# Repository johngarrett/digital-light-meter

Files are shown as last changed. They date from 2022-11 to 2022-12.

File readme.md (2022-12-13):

# About

This project is a digital light meter used for metering photos. 
There were two goals in mind when building this:
1. Let the user track the camera settings for each shot they've taken on a film camera
2. Correctly meter for a scene based on a desired shutter speed or aperture

# Parts
- [Adafruit Feather m0](https://www.adafruit.com/product/2772)
    - built in microSD reader
    - built in battery support 
    - built in serial over microUSB
- [BH1750 Light Sensor](https://learn.adafruit.com/adafruit-bh1750-ambient-light-sensor)
- [SSD1306 OLED Display](https://www.amazon.com/Songhe-0-96-inch-I2C-Raspberry/dp/B085WCRS7C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)
- [ArduCAM OV2640 2MP Plus](https://www.arducam.com/product/arducam-2mp-spi-camera-b0067-arduino/)

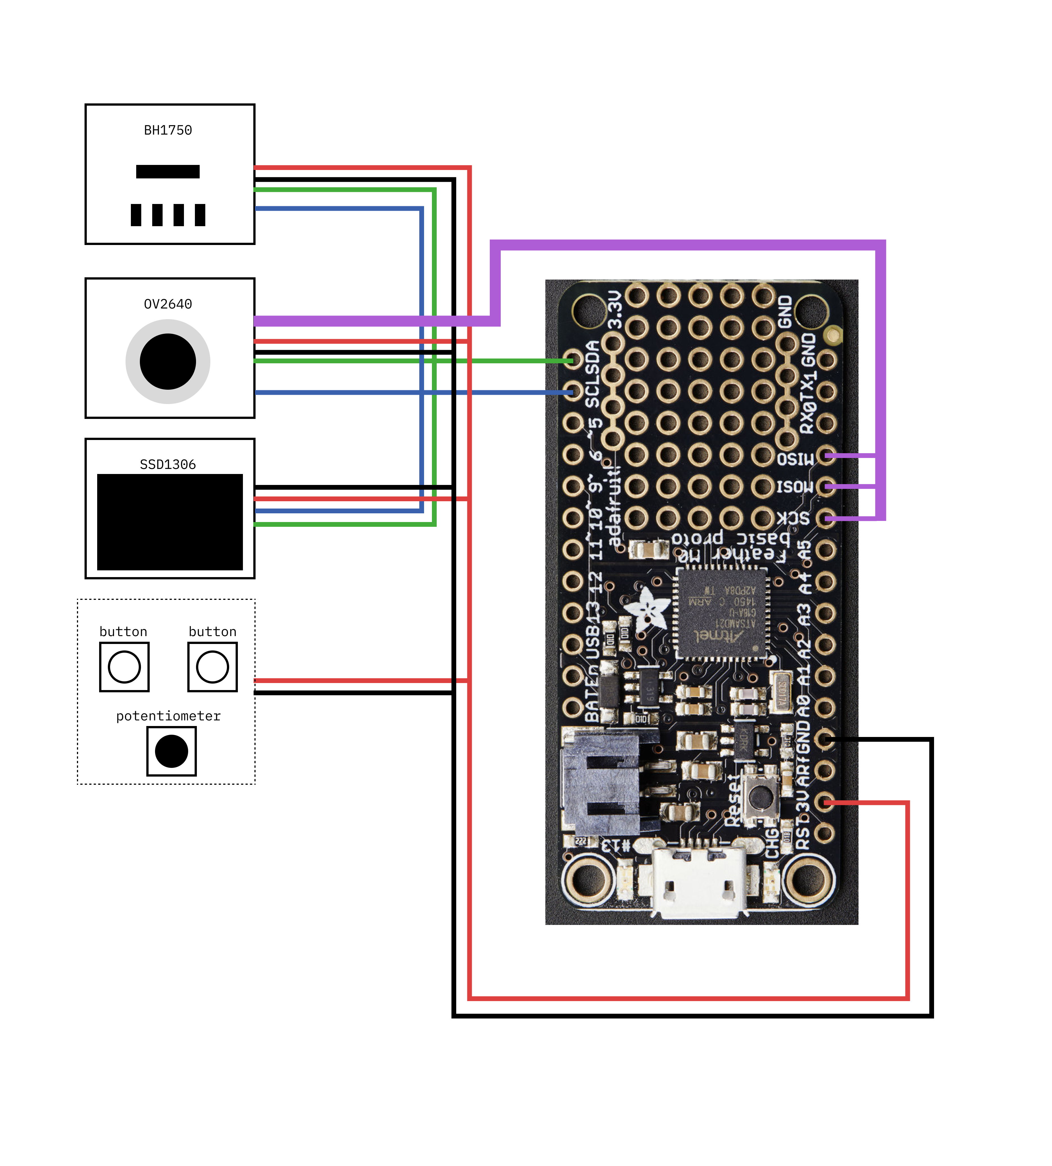
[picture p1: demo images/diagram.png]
diagram

> Some connections aren't shown for simplicity

# Libraries Used
[BH1750](https://github.com/claws/BH1750)
[Adafruit_SSD1306](https://github.com/adafruit/Adafruit_SSD1306)
[ArduCAM/Arduino](https://github.com/ArduCAM/Arduino)

# Results

The final product allows the user to set information about their camera's conditions (like ISO or lens focal length) which persists on the SD card across boots.

When in use, the user can set a desired shutter speed or aperture and the corresponding value will be calculated and displayed. 

They then can hit record and the shot metadata along with a reference photo captured by the OV2640 will be saved to the SD card under the corresponding shot number.

## Screens
### Startup
boot screen

On startup, the following values are read from storage and displayed
- ISO value
- Lens focal length
- Shot number
- Battery percentage
- Battery charge bar
### Main Screen
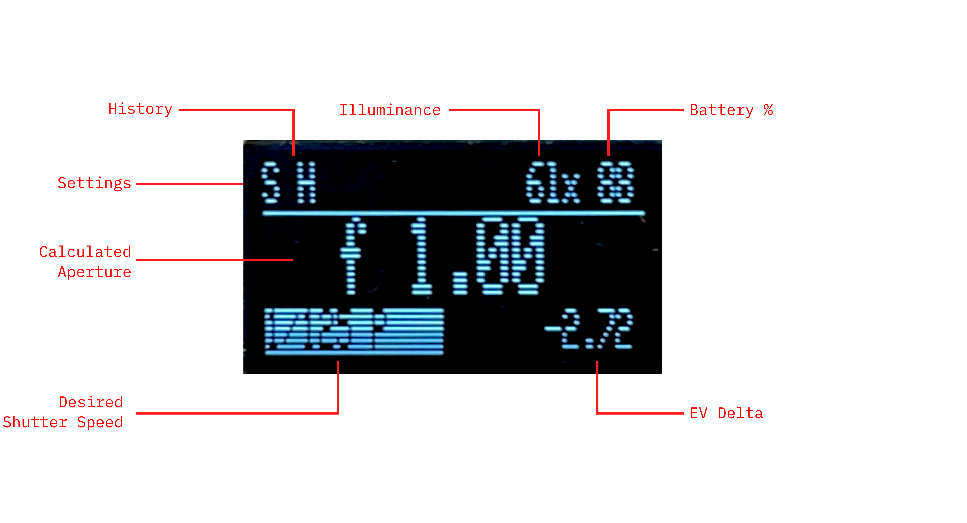
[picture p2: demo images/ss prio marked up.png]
main screen ss prio

> shutter speed priority mode

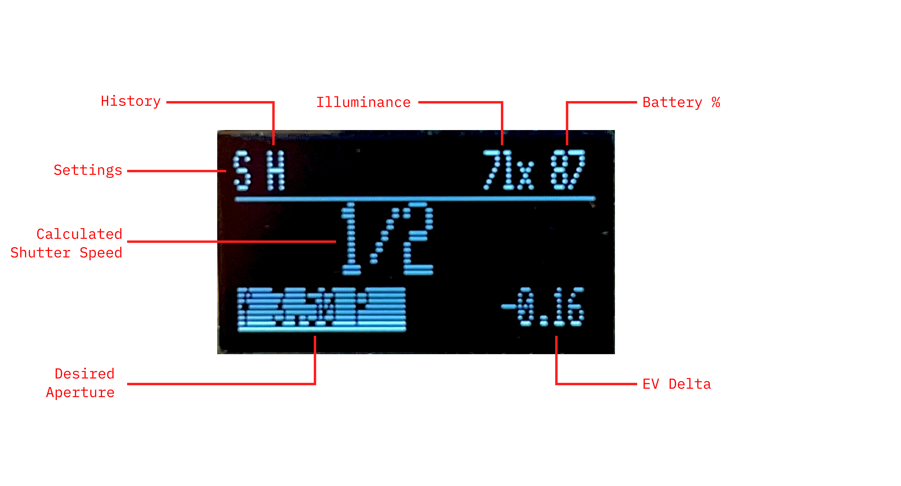
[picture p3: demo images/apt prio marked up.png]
main screen apt prio

> aperture priority mode
### Settings
settings screen
The settings screen allows the user to set the ISO value, lens focal length, illuminance constant, shot number, and list files on SD card.
settings screen ISO
> Adjusting the ISO from settings

settings screen ls all
> Listing the contents of the microSD card from settings

### History
The history screen allows the user to view the shots they've taken and see the contents of each shot
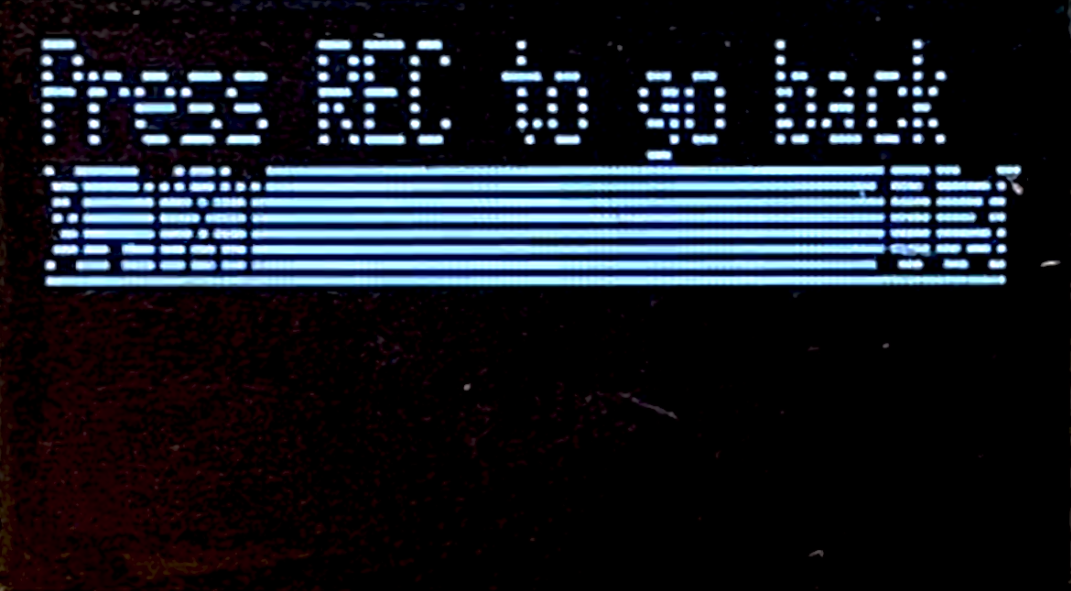
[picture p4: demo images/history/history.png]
history overview

history detail

## Build

Here are images of the light meter device. 

front
back
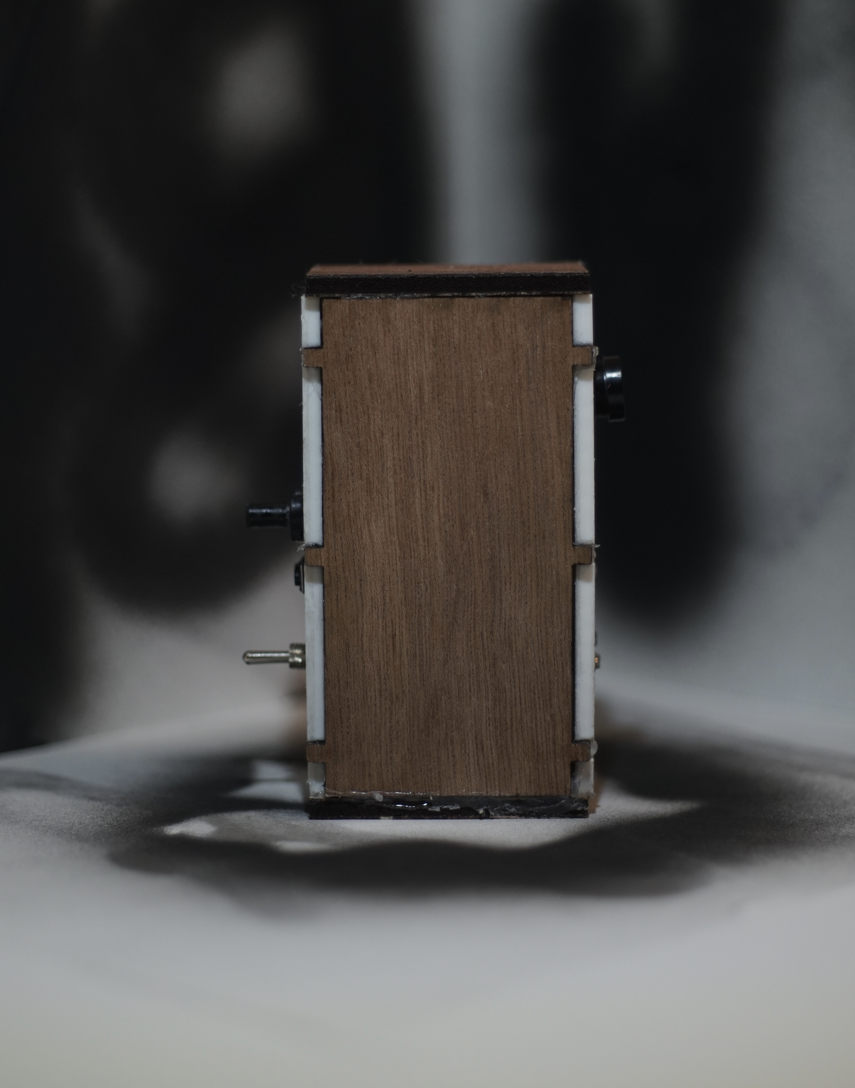
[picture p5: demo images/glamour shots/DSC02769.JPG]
side


The front and back panels were 3d printed and the remaining sides were laser cut from the following design
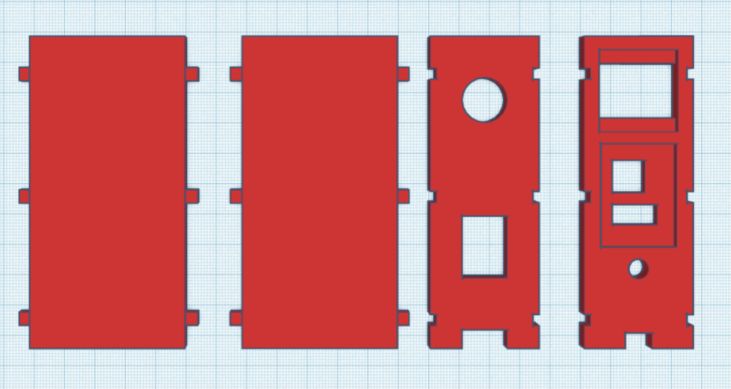
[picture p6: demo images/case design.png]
case design


## Film
To test this device, I shot a roll of Porta 400 film, pushed 1 stop to ISO 800, and metered with this device. Below are two examples from that roll.

### Example Shot 1
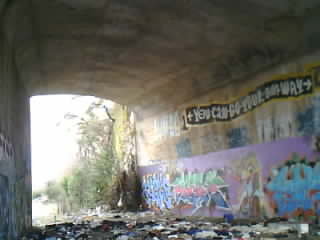
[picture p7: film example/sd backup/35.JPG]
photo under bridge reference

> reference photo from light meter

photo under bridge
> resultant photo

```
ISO 800
CVAL 250
F_LEN 28
PRIO SS
APT 3.50
SS 1/250.00
LUX 1050
EV_ACTUAL 11.71
EV_CALC 11.58
EV_DELTA 0.13
```
> shot settings from light meter

### Example Shot 2
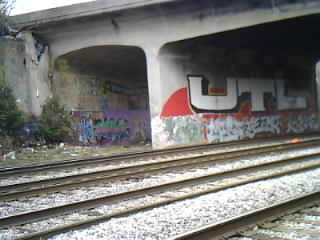
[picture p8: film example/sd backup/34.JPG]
bridge photo reference

> reference photo from light meter

bridge photo
> resultant photo

```
ISO 800
CVAL 250
F_LEN 28
PRIO SS
APT 8.00
SS 1/250.00
LUX 6585
EV_ACTUAL 14.36
EV_CALC 13.97
EV_DELTA 0.40
```
> shot settings from light meter

# Demo Video
[Youtube Link](https://youtu.be/QNY8x09aPGU)

# Retrospective
## Iterative process
### Phases
There were three major phases of this project.

1. The breadboard phase
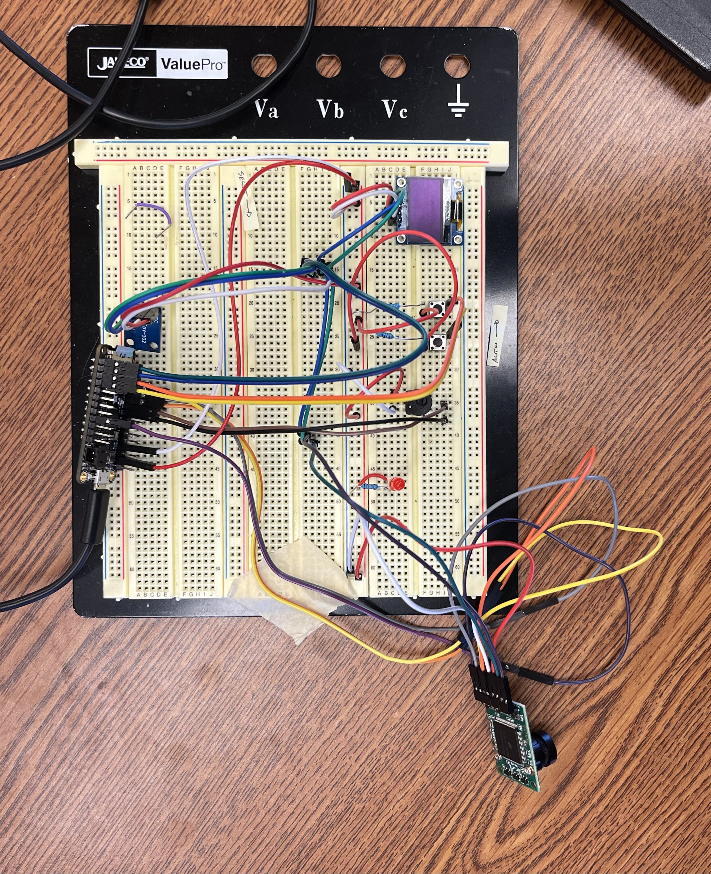
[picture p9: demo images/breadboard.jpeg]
breadboard image

In this phase, every electrical connection was extremely fragile. The device stayed like this for a long time as the software was built out.

2. The cardboard case
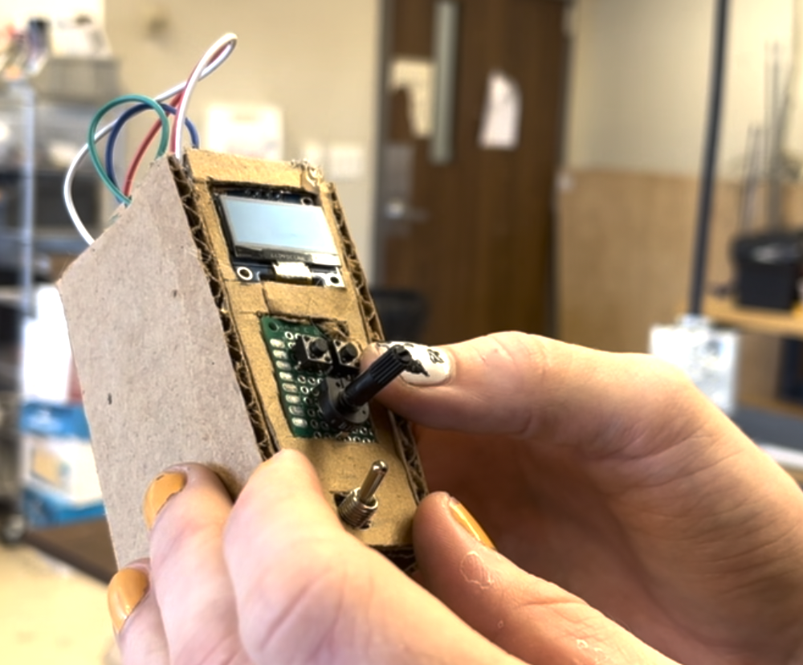
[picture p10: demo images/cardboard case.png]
cardboard case image

This was a good way to estimate the dimensions for the final case and assess the overall feel of the device. In this phase, I was also able to calibrate the calculations as I was able to test a wider variety of conditions

3. The final case

This is the current state of the project and the images can be seen under [build](#Build).

### Things that didn't work
1. Using CircuitPython
[CircuitPython](https://circuitpython.org/) looked to be an easy to use alternative to developing with the Arduino tools but the display library for the SSD1306 immediatly used all the available memory on the feather m0.
2. Displaying images on screen
I really wanted to display the reference images on screen when capturing the image or viewing image history. However, that would require converting the stored JPG to a BMP image, converting each RGB pixel of the BMP image into a single grayscale value, and finally scaling the image down to fit on the 128x32 display. Due to time constraints and minimal ROI, this was scrapped.
3. 3D printing the correct dimensions
The resultant case for this device is partially hand carved because, no matter how many times I measured, the parts didn't fit well into the case. This mixed with the 4 hour printing prevented me from iterating as much as I wished.

## Skills learned

- How to 3D print
- How to laser cut
- The math behind photography exposure
- Designing software on a constrained device
- Making necessary compromises to get to the final product

# References
There were a couple of projects online that used the BH1750 light meter to assess lighting conditions but I only found one that calculated camera settings based on the input value, [linked here](https://create.arduino.cc/projecthub/alankrantas/ardumeter-arduino-incident-light-meter-606f63).

The following wikipedia articles gave me the formulas used for camera setting calculations
[Light meter](https://en.wikipedia.org/wiki/Light_meter)
[Illuminance](https://en.wikipedia.org/wiki/Illuminance)

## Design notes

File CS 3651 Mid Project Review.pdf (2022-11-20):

### Project Description

Our project is a digital light meter for photography. We are using an Adafruit Feather m0 microcontroller, a BH1750 light meter, an SSD1306 OLED display, and an ARDUCAM OV2640. The device will have buttons allowing the user to switch modes and set specific values and use its builtin SD card to save metadata about each photo. The camera will be used to store a reference photo alongside the recorded metadata for a given shot.

We are using the Arduino SDK to develop software for our microcontroller (CircuitPy was too memory inefficient for our device).

The chassis of the device will be a 3d printed case. If time permits, we would like to add a physical trigger for the record button.

### Progress thus far

The pins for the Adafruit Feather m0 and BH1750 light meter have been soldered to their respective boards. The SSD1306 OLED display and light meter are both hooked up to the microcontroller and are being controlled by custom software. After the device turns on, the lux reading is continuously captured from the light meter and printed on the OLED display. We are also able to read and write from the SD card successfully.

The ARDUCAM OV2640 arrived in the mail yesterday and has not yet been integrated.

### Difficulties

There were issues getting the BH1750 library to work properly. The library had to be manually edited and it experiences issues when delays are added into the main program. Further rewrites to the library may be required to convert it to an interrupted driven, asynchronous, design which may help with the timing issues.

The ARDUCAM OV5640 has been tested online to work with our microcontroller model, the Adafruit Feather m0. However, the model of our camera is OV2640. From our research, there is no reason it shouldn’t work with our microcontroller but that is a possibility.

In regards to the class as a whole, I think the skill demos and lecture materials have prepared us well to complete our project.

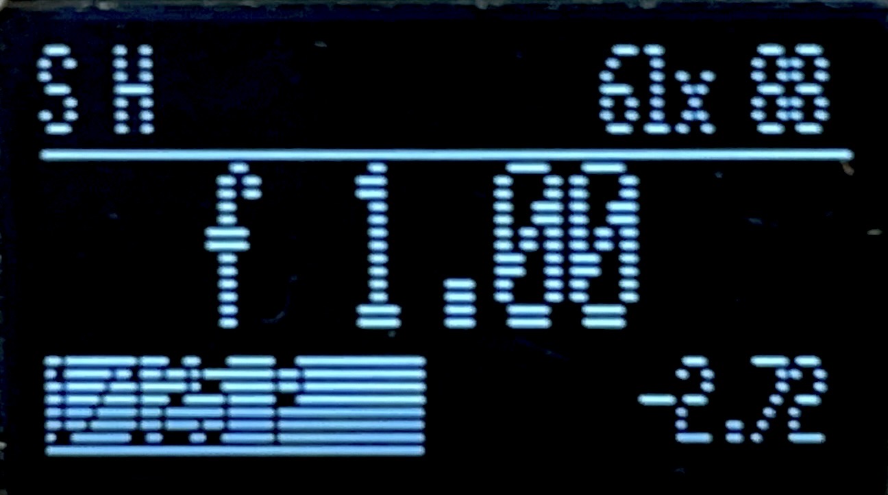
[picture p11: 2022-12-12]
demo images/ss prio.jpg

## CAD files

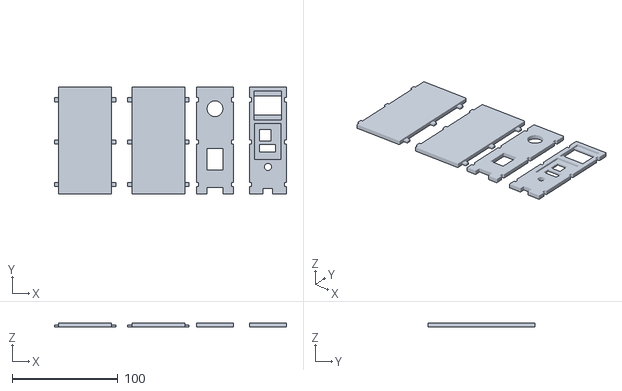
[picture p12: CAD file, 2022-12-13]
lightmeter case.stl
219.0 x 101.0 x 4.00

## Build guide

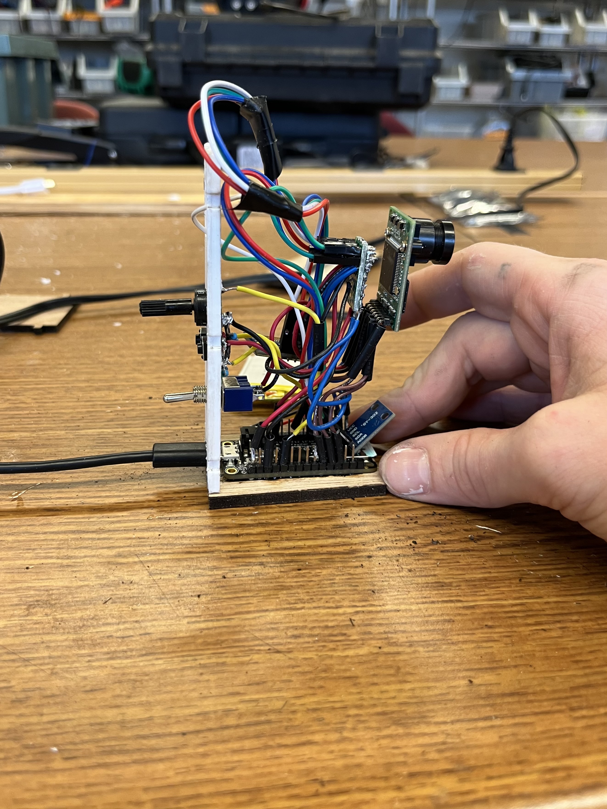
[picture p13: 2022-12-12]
demo images/soldering.jpeg

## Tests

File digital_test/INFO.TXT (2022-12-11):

ISO_IDX 6
SHOT 5
CVAL_IDX 0
F_LEN_IDX 1
PRIO 0
APT_IDX 2
SS_IDX 3

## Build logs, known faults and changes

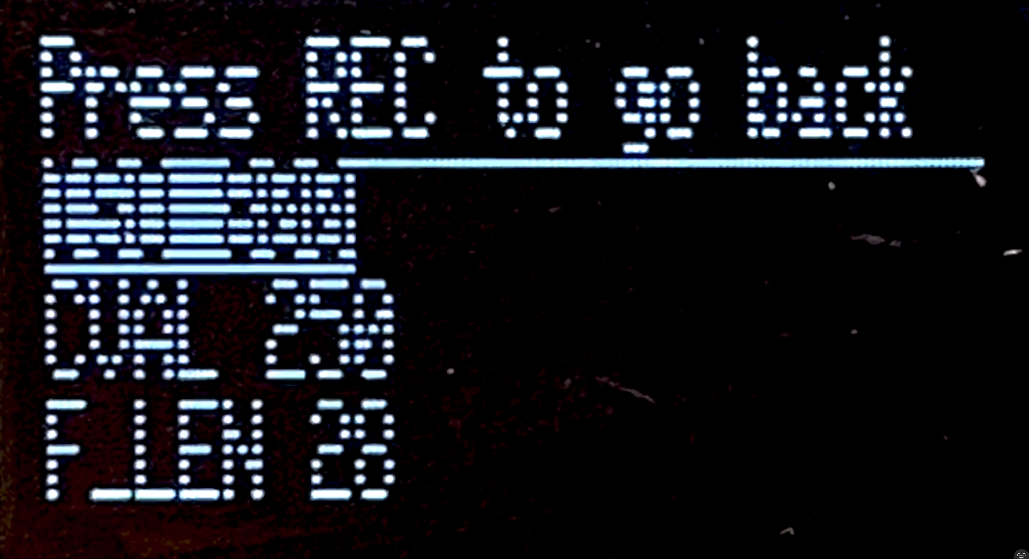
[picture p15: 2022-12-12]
demo images/history/history detail.png

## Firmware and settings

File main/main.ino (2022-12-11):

#include <SPI.h>
#include <Adafruit_GFX.h>
#include <Adafruit_SSD1306.h>
#include <Wire.h>
#include <i2cdetect.h>
#include <math.h> 
#include "libs/BH1750/src/BH1750.h"
#include "memorysaver.h"
#include <SD.h>

#include <ArduCAM.h>
#include <SPI.h>

#define MAX_BAT_VOLT    4.2  // max voltage for lipo battery
#define SCREEN_WIDTH    128
#define SCREEN_HEIGHT   32
#define OLED_RESET      -1   // Reset pin # (or -1 if sharing Arduino reset pin)
#define SCREEN_ADDRESS  0x3C // 0x3D for 128x64, 0x3C for 128x32

#define SD_CS   4
#define SPI_CS  12
#define SEL_PIN 10
#define REC_PIN 6
#define POT_PIN A1
#define BAT_PIN A7

const double APT_TABLE[]  = { 1.0, 1.4, 1.8, 2.0, 2.8, 3.5, 4.0, 4.5, 5.6, 6.3, 8.0, 11.0, 12.7, 16.0, 22.0, 32.0 };
const int ISO_TABLE[]     = { 6, 12, 25, 50, 100, 160, 200, 400, 800, 1600, 3200, 6400 };
const double SS_TABLE[]   = { -1, 1, 2, 4, 8, 15, 30, 60, 125, 250, 500, 1000 };
const int C_TABLE[]       = { 250, 330 }; // incident constant
const int FL_TABLE[]      = { 28, 50 }; // focal length

const int apt_tbl_sz = sizeof(APT_TABLE) / sizeof(APT_TABLE[0]);
const int iso_tbl_sz = sizeof(ISO_TABLE) / sizeof(ISO_TABLE[0]);
const int ss_tbl_sz = sizeof(SS_TABLE) / sizeof(SS_TABLE[0]);
const int c_tbl_sz = sizeof(C_TABLE) / sizeof(C_TABLE[0]);
const int fl_tbl_sz = sizeof(FL_TABLE) / sizeof(FL_TABLE[0]);

enum mode { MODE_BOOTUP, MODE_SS, MODE_SS_EDIT, MODE_APT, MODE_APT_EDIT, MODE_SETTINGS, MODE_SETTINGS_EDIT, MODE_HISTORY, MODE_HISTORY_EDIT, MODE_RECORD };
enum priority { APT_PRIO, SS_PRIO };

Adafruit_SSD1306 display(SCREEN_WIDTH, SCREEN_HEIGHT, &Wire, OLED_RESET);
ArduCAM camera(OV2640, SPI_CS);
BH1750 lightMeter;

long lux;
double actual_ev, calc_ev, ev_delta = 0;
int apt_indx, iso_indx, ss_indx, fl_indx, c_indx = 0;
int shot_number = 0;
int sel_state = 0;
int rec_state = 0;
int pot_val = 0;
float bat_val = 0;
int recorded_ss_indx, recorded_apt_indx = 0;
bool camera_initialized = false;
bool sd_available = false;

mode selected_mode = MODE_BOOTUP;
priority selected_prio = APT_PRIO;

void setup() {
  Serial.begin(9600);
  //while (!Serial) { }
  Wire.begin();

  if (lightMeter.begin(BH1750::CONTINUOUS_HIGH_RES_MODE, 0x23, &Wire)) {
    Serial.println(F("Light meter initialized"));
  } else {
    Serial.println(F("Error initing lightmeter"));
  }

  if(!display.begin(SSD1306_SWITCHCAPVCC, SCREEN_ADDRESS)) {
    Serial.println(F("SSD1306 allocation failed"));
    for(;;); // Don't proceed, loop forever
  }

  sd_available = SD.begin(SD_CS);

  if (!sd_available) {
    Serial.println(F("SD Card failed to initialize!"));
  }

  pinMode(SEL_PIN, INPUT);
  pinMode(REC_PIN, INPUT);

  // read values from SD card for APT, ISO, SS, etc.
  read_stored_values();
}

// display ISO, F-length, and shot number on bootup
int bootup_countdown = 75;
void display_bootup_screen() {
  // the default mode is MODE_BOOTUP, keep it that way until bootup_countdown reaches 0
  bootup_countdown--;

  if (bootup_countdown == 0) {
    selected_mode = MODE_SETTINGS;
  }

  display.clearDisplay();
  display.setTextSize(1);
  display.setCursor(0,0);

  display.setTextColor(SSD1306_WHITE);

  print_left_1x(String("ISO ") + String(ISO_TABLE[iso_indx]));
  print_right_1x(String("F-Len ") + String(FL_TABLE[fl_indx]));
  display.println();
  print_center_2x(String("Shot #") + String(shot_number));
  display.println('\n');

  // drawing battery percentage

  display.print(int((bat_val / MAX_BAT_VOLT) * 100));
  display.print("% ");
  int x = display.getCursorX();
  int y = display.getCursorY();
  int bar_width = (bat_val / MAX_BAT_VOLT) * (display.width() - x);

  for (int yoff = 0; yoff < 6; ++yoff) {
    display.drawFastHLine(x, y + yoff, bar_width, SSD1306_WHITE);
  }

  display.display();
}

void setup_camera() {
  uint8_t vid, pid, temp;
  pinMode(SPI_CS, OUTPUT);
  digitalWrite(SPI_CS, HIGH);
  SPI.begin();

  // reset CPLD
  camera.write_reg(0x07, 0x80);
  delay(100);
  camera.write_reg(0x07, 0x00);
  delay(100);

  while(1) { // TODO: only loop a few times orr don't loop at all
    //Check if the ArduCAM SPI bus is OK
    camera.write_reg(ARDUCHIP_TEST1, 0x55);
    temp = camera.read_reg(ARDUCHIP_TEST1);
    
    if (temp != 0x55) {
      Serial.println(F("SPI interface Error!"));
      delay(1000);
      continue;
    } else {
      Serial.println(F("SPI interface OK."));
      break;
    }
  }

  while(1) {
    //Check if the camera module type is OV2640
    camera.wrSensorReg8_8(0xff, 0x01);
    camera.rdSensorReg8_8(OV2640_CHIPID_HIGH, &vid);
    camera.rdSensorReg8_8(OV2640_CHIPID_LOW, &pid);
    if ((vid != 0x26) && ((pid != 0x41) || (pid != 0x42))) {
      Serial.println(F("Can't find OV2640 module!"));
      delay(1000);
      continue;
    } else {
      Serial.println(F("OV2640 detected."));
      break;
    }
  }
  camera.set_format(JPEG);
  camera.InitCAM();
  camera.OV2640_set_JPEG_size(OV2640_320x240);
  camera_initialized = true;
}

void loop() {
  read_inputs();
  handle_inputs();
  read_lux();
  calculate_stats();
  display_info();

  // don't hang the bootup process
  if (!camera_initialized) {
    setup_camera();
  }
}

void read_inputs() {
  sel_state = digitalRead(SEL_PIN);
  rec_state = digitalRead(REC_PIN);
  pot_val = analogRead(POT_PIN);
  // battery value calculation 
  // https://learn.adafruit.com/adafruit-feather-m0-adalogger/power-management
  bat_val = analogRead(BAT_PIN);
  bat_val *= 2;
  bat_val *= 3.3; // reference voltage
  bat_val /= 1024; // convert to voltage
}

boolean on_main_screen() {
  return selected_mode == MODE_SETTINGS || selected_mode == MODE_HISTORY || selected_mode == MODE_SS || selected_mode == MODE_APT;
}

boolean on_edit_screen() {
  return selected_mode == MODE_SETTINGS_EDIT || selected_mode == MODE_HISTORY_EDIT || selected_mode == MODE_APT_EDIT || selected_mode == MODE_SS_EDIT;
}


void handle_inputs() {
  // pass control over to the settings file
  if (selected_mode == MODE_SETTINGS_EDIT) {
    handle_settings_input();
    return;
  }

  if (selected_mode == MODE_HISTORY_EDIT) {
    handle_history_input();
    return;
  }

  if (selected_mode == MODE_RECORD) {
    handle_record_input();
    return;
  }

  if (rec_state == 1) {
    selected_mode = MODE_RECORD;
    recorded_apt_indx = apt_indx;
    recorded_ss_indx = ss_indx;
    capture_image();
    delay(175);
  }

  // switching between parent and child view
  if (sel_state == 1) {
    switch (selected_mode) {
      case MODE_APT:
        selected_mode = MODE_APT_EDIT;
        break;
      case MODE_APT_EDIT:
        update_stored_info();
        selected_mode = MODE_APT;
        break;
      case MODE_SS:
        selected_mode = MODE_SS_EDIT;
        break;
      case MODE_SS_EDIT:
        update_stored_info();
        selected_mode = MODE_SS;
        break;
      case MODE_SETTINGS:
        selected_mode = MODE_SETTINGS_EDIT;
        break;
      case MODE_HISTORY:
        selected_mode = MODE_HISTORY_EDIT;
        break;
    }
    delay(175); // to prevent jittering
  }

  // the user wants to set a value to be automatically decided
  if (on_main_screen()) {
    // map pot val to { SET, HIST, SS, APT } (3x for better error handling)
    switch (map(pot_val, 0, 1023, 1, 12)) {
      case 1:
      case 2:
      case 3:
        selected_mode = MODE_SETTINGS;
        break;
      case 4:
      case 5:
      case 6:
        selected_mode = MODE_HISTORY;
        break;
      case 7:
      case 8:
      case 9:
        // ordering changes based on priority
        selected_mode = (selected_prio == APT_PRIO) ? MODE_SS : MODE_APT;
        break;
      case 10:
      case 11:
      case 12:
        selected_mode = (selected_prio == SS_PRIO) ? MODE_SS : MODE_APT;
        break;
    }
  }

  if (selected_mode == MODE_SS_EDIT) {
    selected_prio = SS_PRIO;
    ss_indx = map(pot_val, 0, 1023, 0, ss_tbl_sz);
    if (ss_indx  == ss_tbl_sz) {
      ss_indx--;
    }
  }

  if (selected_mode == MODE_APT_EDIT) {
    selected_prio = APT_PRIO;
    apt_indx = map(pot_val, 0, 1023, 0, apt_tbl_sz);
    if (apt_indx == apt_tbl_sz) {
      apt_indx--;
    }
  }
}

void read_lux() {
  lux = lightMeter.readLightLevel();
  if (lux == -1) {
    lightMeter.begin(BH1750::CONTINUOUS_HIGH_RES_MODE, 0x23, &Wire);
  }
}

// calculate necessary SS, APT based on prio and lux
void calculate_stats() {
  actual_ev = log2((lux * ISO_TABLE[iso_indx]) / C_TABLE[c_indx]);
  /*
    N^2 / t = ES / C

    N = apeture
    t = shutter speed (in seconds)
    E = illuminance
    S = ISO arithmetic speed
    C = incident-light constant
   */
  if (selected_prio == APT_PRIO) {
    /*
       t = (N^2 * C) / ES
     */


    // calculate SS 
    double apt = APT_TABLE[apt_indx];
    double ss = pow(2.0, actual_ev) / pow(apt, 2.0);

    // search for closest shutter speed
    for (int i = 0; i < ss_tbl_sz - 1; ++i) {
      if (ss >= SS_TABLE[i] && ss <= SS_TABLE[i+1]) {
        if (abs(ss - SS_TABLE[i]) <= abs(ss - SS_TABLE[i+1])) {
          ss_indx = i;
        } else {
          ss_indx = i + 1;
        }
      }
    }
  } else {
    // calculate APT 
    double ss = SS_TABLE[ss_indx];
    double apt = sqrt(pow(2.0, actual_ev) / ss);

    // search for closest apt 
    for (int i = 0; i < apt_tbl_sz - 1; ++i) {
      if (apt >= APT_TABLE[i] && apt <= APT_TABLE[i+1]) {
        if (abs(apt - APT_TABLE[i]) <= abs(apt - APT_TABLE[i+1])) {
          apt_indx = i;
        } else {
          apt_indx = i + 1;
        }
      }
    }
  }

  // calculate ev detla
  calc_ev = log2(pow(APT_TABLE[apt_indx], 2.0) / (1.0 / SS_TABLE[ss_indx]));

  ev_delta = actual_ev - calc_ev;
}

void display_info() {
  if (on_edit_screen()) {
    display_editing_screen();
    return;
  }

  if (selected_mode == MODE_RECORD) {
    show_recording();
    return;
  }

  if (selected_mode == MODE_BOOTUP) {
    display_bootup_screen();
    return;
  }

  display.clearDisplay();
  display.setTextSize(1);
  display.setCursor(0,0);

  selected_mode == MODE_SETTINGS ? display.setTextColor(SSD1306_BLACK, SSD1306_WHITE) : display.setTextColor(SSD1306_WHITE);
  display.print("S");
  display.setTextColor(SSD1306_WHITE);
  display.print(" ");
  selected_mode == MODE_HISTORY ? display.setTextColor(SSD1306_BLACK, SSD1306_WHITE) : display.setTextColor(SSD1306_WHITE);
  display.print("H");

  display.setTextColor(SSD1306_WHITE);
  print_right_1x(int(lux) + String("lx ") + int((bat_val / MAX_BAT_VOLT) * 100));


  display.println();
  display.drawFastHLine(0, display.getCursorY(), display.width(), SSD1306_WHITE);

  if (selected_prio == SS_PRIO) {
    /*
        |    APT    |
        |    APT    |
        | ss     ev |
    */
    selected_mode == MODE_APT ? display.setTextColor(SSD1306_BLACK, SSD1306_WHITE) : display.setTextColor(SSD1306_WHITE);
    print_center_2x(String("f ") + String(APT_TABLE[apt_indx]) + String((selected_prio == APT_PRIO ? " P" : "")));
    display.println("\n"); // two new lines

    selected_mode == MODE_SS ? display.setTextColor(SSD1306_BLACK, SSD1306_WHITE) : display.setTextColor(SSD1306_WHITE);
    print_left_1x(String("1/") + String(int(SS_TABLE[ss_indx])) + String((selected_prio == SS_PRIO ? " P" : "")));

    display.setTextColor(SSD1306_WHITE);
    print_right_1x(String(ev_delta));
  } else {
    /*
        |    SS     |
        |    SS     |
        | apt    ev |
    */
    selected_mode == MODE_SS ? display.setTextColor(SSD1306_BLACK, SSD1306_WHITE) : display.setTextColor(SSD1306_WHITE);
    print_center_2x(String("1/") + String(int(SS_TABLE[ss_indx])) + String((selected_prio == SS_PRIO ? " P" : "")));
    display.println("\n"); // two new lines

    selected_mode == MODE_APT ? display.setTextColor(SSD1306_BLACK, SSD1306_WHITE) : display.setTextColor(SSD1306_WHITE);
    print_left_1x(String("f ") + String(APT_TABLE[apt_indx]) + String((selected_prio == APT_PRIO ? " P" : "")));

    display.setTextColor(SSD1306_WHITE);
    print_right_1x(String(ev_delta));
  }

  display.println();
  display.display();
}

// when the user is editing a menu item
void display_editing_screen() {
  switch (selected_mode) {
    case MODE_SETTINGS_EDIT:
      show_settings();
      break;
    case MODE_HISTORY_EDIT:
      show_history();
      break;
    case MODE_SS_EDIT:
      render_edit_screen("SS", String("1/") + String(SS_TABLE[ss_indx]));
      break;
    case MODE_APT_EDIT:
      render_edit_screen("APETURE", String("f ") + String(APT_TABLE[apt_indx]));
      break;
  }
}

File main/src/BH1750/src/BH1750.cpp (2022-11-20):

/*

  This is a library for the BH1750FVI Digital Light Sensor breakout board.

  The BH1750 board uses I2C for communication. Two pins are required to
  interface to the device. Configuring the I2C bus is expected to be done
  in user code. The BH1750 library doesn't do this automatically.

  Written by Christopher Laws, March, 2013.

*/

#include "BH1750.h"

// Define milliseconds delay for ESP8266 platform
#if defined(ESP8266)

#  include <pgmspace.h>
#  define _delay_ms(ms) delayMicroseconds((ms)*1000)

// Use _delay_ms from utils for AVR-based platforms
#elif defined(__avr__)
#  include <util/delay.h>

// Use Wiring's delay for compability with another platforms
#else
#  define _delay_ms(ms) delay(ms)
#endif

// Legacy Wire.write() function fix
#if (ARDUINO >= 100)
#  define __wire_write(d) I2C->write(d)
#else
#  define __wire_write(d) I2C->send(d)
#endif

// Legacy Wire.read() function fix
#if (ARDUINO >= 100)
#  define __wire_read() I2C->read()
#else
#  define __wire_read() I2C->receive()
#endif

/**
 * Constructor
 * @params addr Sensor address (0x76 or 0x72, see datasheet)
 *
 * On most sensor boards, it was 0x76
 */
BH1750::BH1750(byte addr) {

  BH1750_I2CADDR = addr;
  // Allows user to change TwoWire instance
  I2C = &Wire;
}

/**
 * Configure sensor
 * @param mode Measurement mode
 * @param addr Address of the sensor
 * @param i2c TwoWire instance connected to I2C bus
 */
bool BH1750::begin(Mode mode, byte addr, TwoWire* i2c) {
  Serial.print("[BH1750] began with mode=");
  Serial.print(mode);
  Serial.print(" addr=");
  Serial.print(addr);
  Serial.print(" i2c exists?=");
  Serial.println(i2c != 0);

  // I2C is expected to be initialized outside this library
  // But, allows a different address and TwoWire instance to be used
  if (i2c) {
    I2C = i2c;
  }
  if (addr) {
    BH1750_I2CADDR = addr;
  }

  // Configure sensor in specified mode and set default MTreg
  return (configure(mode) && setMTreg(BH1750_DEFAULT_MTREG));
}

/**
 * Configure BH1750 with specified mode
 * @param mode Measurement mode
 */
bool BH1750::configure(Mode mode) {

  // default transmission result to a value out of normal range
  byte ack = 5;
  byte res = 0;

  // Check measurement mode is valid
  switch (mode) {

  case BH1750::CONTINUOUS_HIGH_RES_MODE:
  case BH1750::CONTINUOUS_HIGH_RES_MODE_2:
  case BH1750::CONTINUOUS_LOW_RES_MODE:
  case BH1750::ONE_TIME_HIGH_RES_MODE:
  case BH1750::ONE_TIME_HIGH_RES_MODE_2:
  case BH1750::ONE_TIME_LOW_RES_MODE:

    // Send mode to sensor
    /*
    I2C->beginTransmission(BH1750_I2CADDR);
    //__wire_write((uint8_t)BH1750_POWER_ON);
    I2C->write((uint8_t)BH1750_POWER_ON);
    res = I2C->endTransmission();
    Serial.print("Power on res:");
    Serial.println(res);
    _delay_ms(120);
    */

    I2C->beginTransmission(BH1750_I2CADDR);
    //__wire_write((uint8_t)mode);
    I2C->write((uint8_t)mode);
    ack = I2C->endTransmission();
    Serial.print("Mode set res:");
    Serial.println(ack);

    // Wait a few moments to wake up
    _delay_ms(120);
    break;

  default:
    // Invalid measurement mode
    Serial.println(F("[BH1750] ERROR: Invalid mode"));
    break;
  }

    BH1750_MODE = mode;
    lastReadTimestamp = millis();
    return true;
  // Check result code
  switch (ack) {
  case 0:
    BH1750_MODE = mode;
    lastReadTimestamp = millis();
    return true;
  case 1: // too long for transmit buffer
    Serial.println(F("[BH1750] ERROR: too long for transmit buffer"));
    break;
  case 2: // received NACK on transmit of address
    Serial.println(F("[BH1750] ERROR: received NACK on transmit of address"));
    break;
  case 3: // received NACK on transmit of data
    Serial.println(F("[BH1750] ERROR: received NACK on transmit of data"));
    break;
  case 4: // other error
    Serial.println(F("[BH1750] ERROR: other error"));
    break;
  default:
    Serial.println(F("[BH1750] ERROR: undefined error"));
    break;
  }

  return false;
}

/**
 * Configure BH1750 MTreg value
 * MT reg = Measurement Time register
 * @param MTreg a value between 31 and 254. Default: 69
 * @return bool true if MTReg successful set
 * 		false if MTreg not changed or parameter out of range
 */
bool BH1750::setMTreg(byte MTreg) {
  if (MTreg < BH1750_MTREG_MIN || MTreg > BH1750_MTREG_MAX) {
    Serial.println(F("[BH1750] ERROR: MTreg out of range"));
    return false;
  }
  byte ack = 5;
  // Send MTreg and the current mode to the sensor
  //   High bit: 01000_MT[7,6,5]
  //    Low bit: 011_MT[4,3,2,1,0]
  I2C->beginTransmission(BH1750_I2CADDR);
  __wire_write((0b01000 << 3) | (MTreg >> 5));
  ack = I2C->endTransmission();
  I2C->beginTransmission(BH1750_I2CADDR);
  __wire_write((0b011 << 5) | (MTreg & 0b11111));
  ack = ack | I2C->endTransmission();
  I2C->beginTransmission(BH1750_I2CADDR);
  __wire_write(BH1750_MODE);
  ack = ack | I2C->endTransmission();

  // Wait a few moments to wake up
  _delay_ms(10);

  // Check result code
  switch (ack) {
  case 0:
    BH1750_MTreg = MTreg;
    return true;
  case 1: // too long for transmit buffer
    Serial.println(F("[BH1750] ERROR: too long for transmit buffer"));
    break;
  case 2: // received NACK on transmit of address
    Serial.println(F("[BH1750] ERROR: received NACK on transmit of address"));
    break;
  case 3: // received NACK on transmit of data
    Serial.println(F("[BH1750] ERROR: received NACK on transmit of data"));
    break;
  case 4: // other error
    Serial.println(F("[BH1750] ERROR: other error"));
    break;
  default:
    Serial.println(F("[BH1750] ERROR: undefined error"));
    break;
  }

  return false;
}
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

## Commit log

2022-11-21 redesign home and settings screen
    [display_helper.ino, main.ino, settings.ino]
2022-11-27 track capture repo and fix its code
    [main.ino]
2022-11-27 minor cleanup. stopped working: wiring issues?
2022-12-02 setup camera on initialization
2022-12-02 correctly read info on boot
    [main.ino, record.ino, settings.ino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]
2022-12-05 add battery percentage in settings
2022-12-07 dont init camera on setup
2022-12-07 battery percentage meter on bootup
2022-12-11 add lux and battery percentage to status bar
2022-12-12 track glamour shots
2022-12-13 track film exports
2022-12-13 add skills learned and 3d case design
    [lightmeter case.stl]
